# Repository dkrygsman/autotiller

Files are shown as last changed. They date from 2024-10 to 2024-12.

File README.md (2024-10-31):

# Linear Actuator Project

## Overview 
3d modeled and printed linear actuator, all stl files are included and links to parts. Printed with PLA I will eventually make useing PETG when everything is working together.

## Next Steps
Project will include details with motor, h-bridge, and C code for usable functions. Maybe use a stepper motor. 

## Parts
Threaded rod on amazon [Here](https://www.amazon.com/gp/product/B07D7WVN1G/ref=ppx_yo_dt_b_search_asin_title?ie=UTF8&psc=1)

Ten turn potentiometer on amazon (would recommend buying from a name brand) [Here](https://www.amazon.com/gp/product/B079JN626M/ref=ppx_yo_dt_b_search_asin_title?ie=UTF8&psc=1)

Belt pullies on amazon [Here](https://www.amazon.com/gp/product/B07RBNK8LN/ref=ppx_yo_dt_b_search_asin_title?ie=UTF8&th=1)

Belts on amazon [Here](https://www.amazon.com/gp/product/B0BZNSJ34B/ref=ppx_yo_dt_b_search_asin_title?ie=UTF8&th=1)

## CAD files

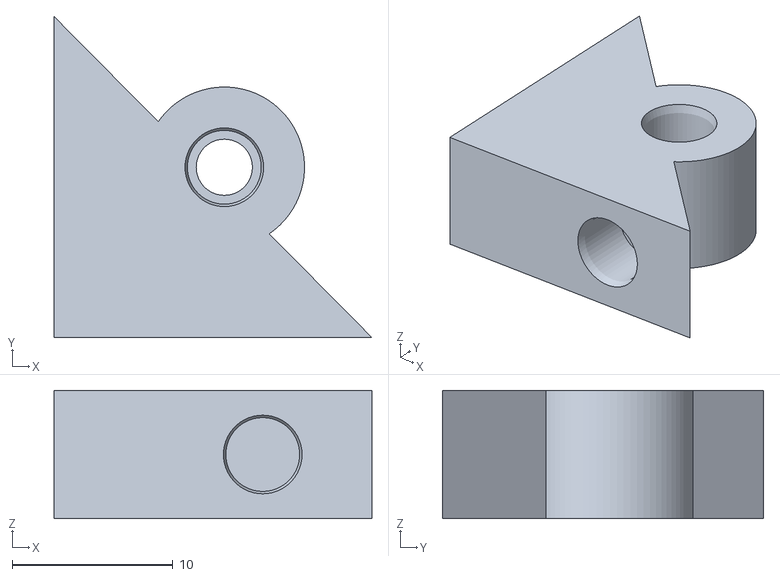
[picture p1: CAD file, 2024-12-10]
stl_files/enclosures/linear_act_wall_to_wall_to_top_bracket.stl
19.8 x 20.0 x 8.00

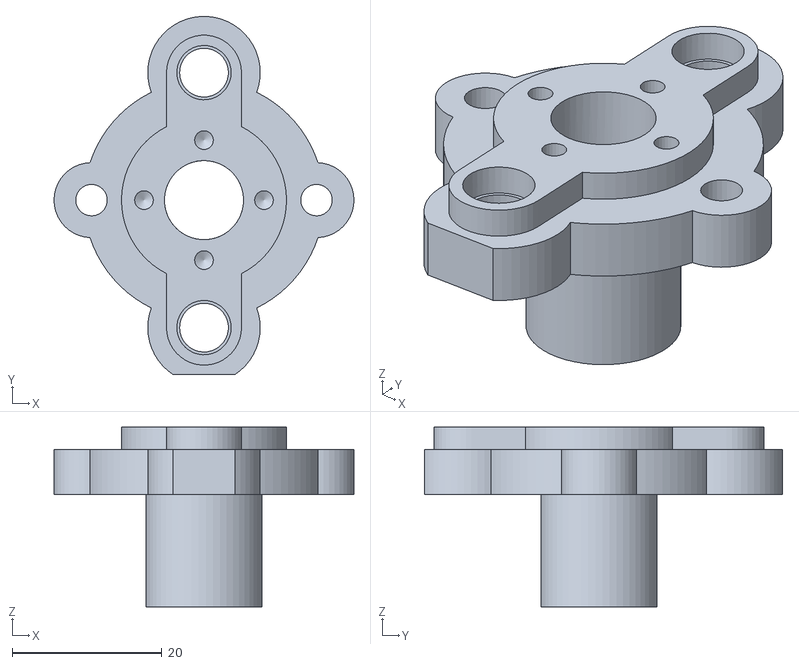
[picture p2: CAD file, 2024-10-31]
stl_files/end_cap.stl
40.0 x 47.7 x 24.0

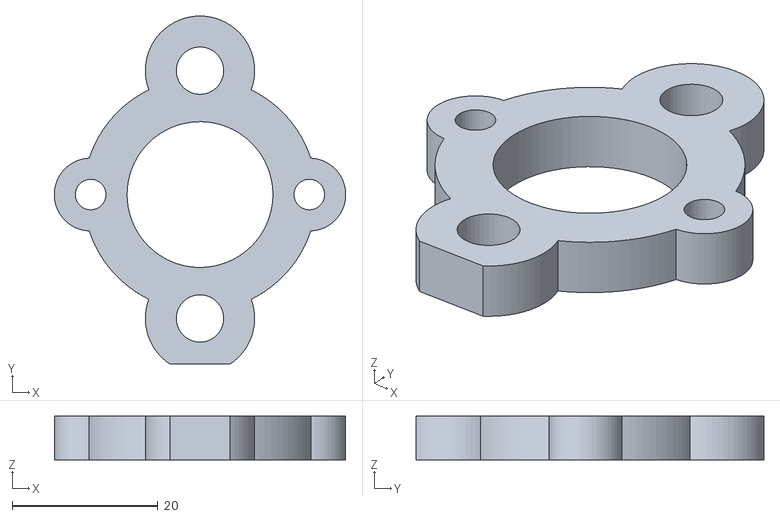
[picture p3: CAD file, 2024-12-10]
stl_files/linear_actuator/slide_end_cap.stl
40.0 x 47.8 x 6.00

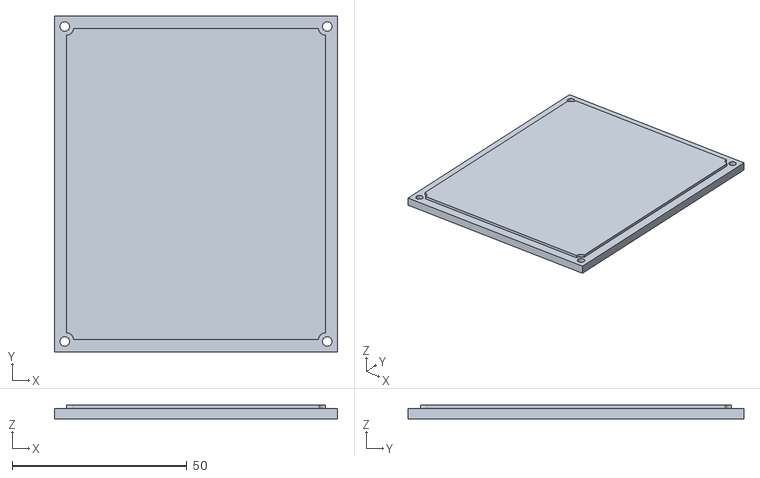
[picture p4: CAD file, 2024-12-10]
stl_files/enclosures/stm32_enclosure_lid.stl
81.0 x 96.0 x 4.00

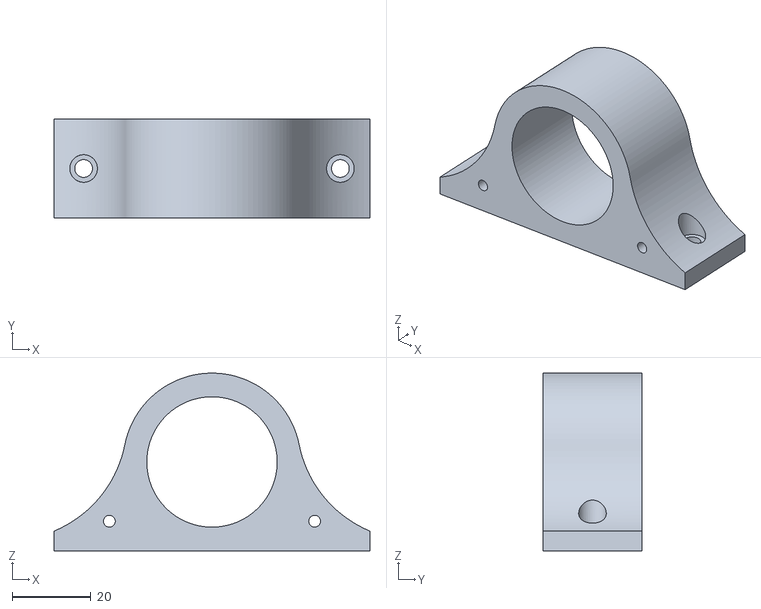
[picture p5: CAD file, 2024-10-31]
stl_files/linear_actuator/motor_holder.stl
80.0 x 25.0 x 45.0

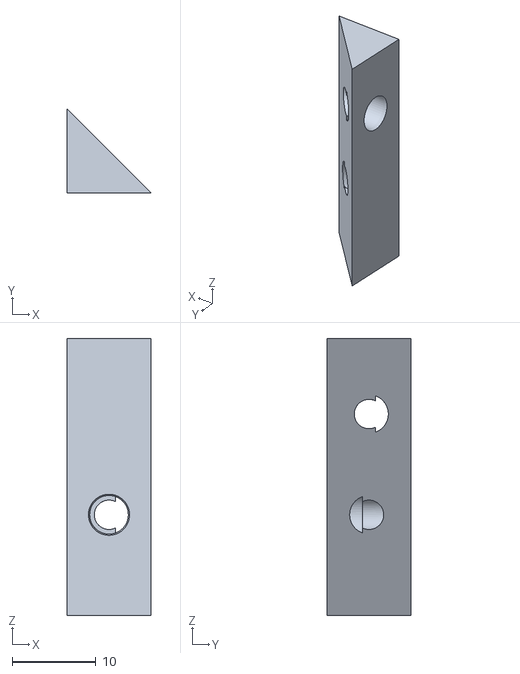
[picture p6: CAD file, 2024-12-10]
stl_files/enclosures/linear_act_base_to_wall_bracket.stl
10.0 x 10.0 x 33.0

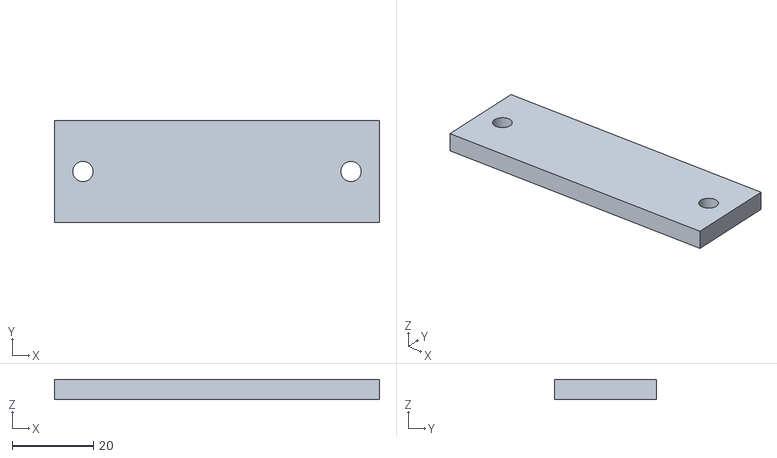
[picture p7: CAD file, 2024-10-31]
stl_files/linear_actuator/motor_base_lifter.stl
80.0 x 25.0 x 5.00

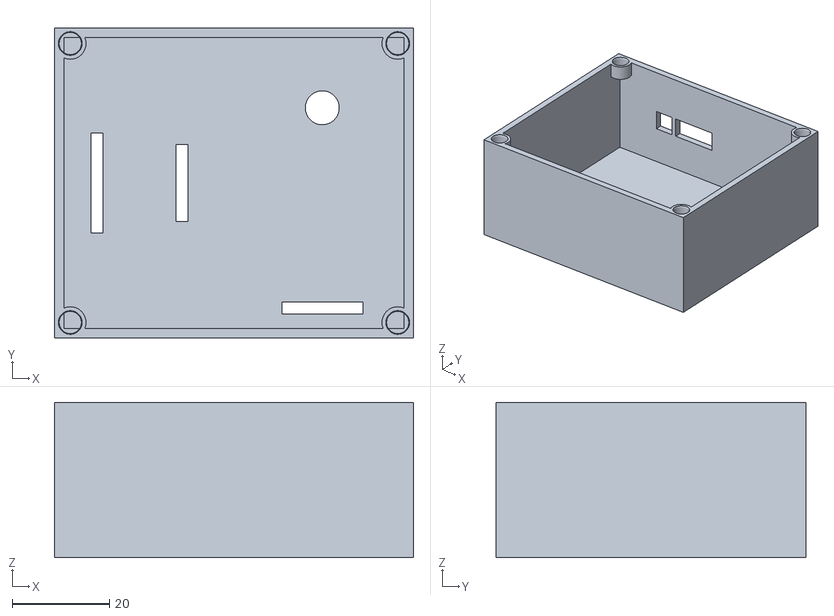
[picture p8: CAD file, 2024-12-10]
stl_files/enclosures/sensor_enclosure.stl
74.0 x 64.0 x 32.0

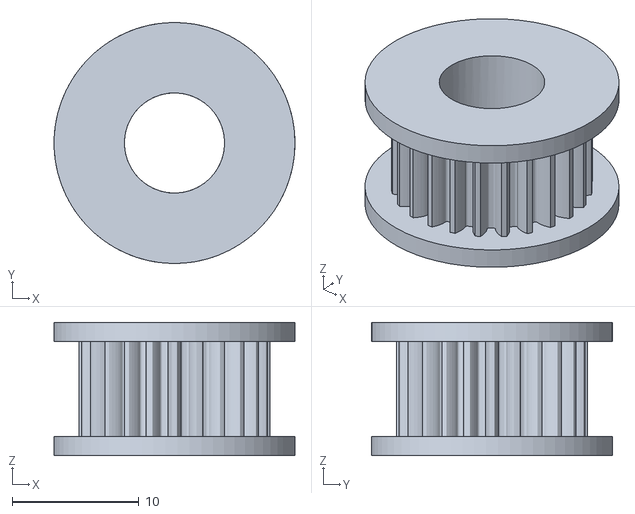
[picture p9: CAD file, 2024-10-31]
stl_files/linear_actuator/threaded_rod_gear7.8.stl
19.0 x 19.0 x 10.5

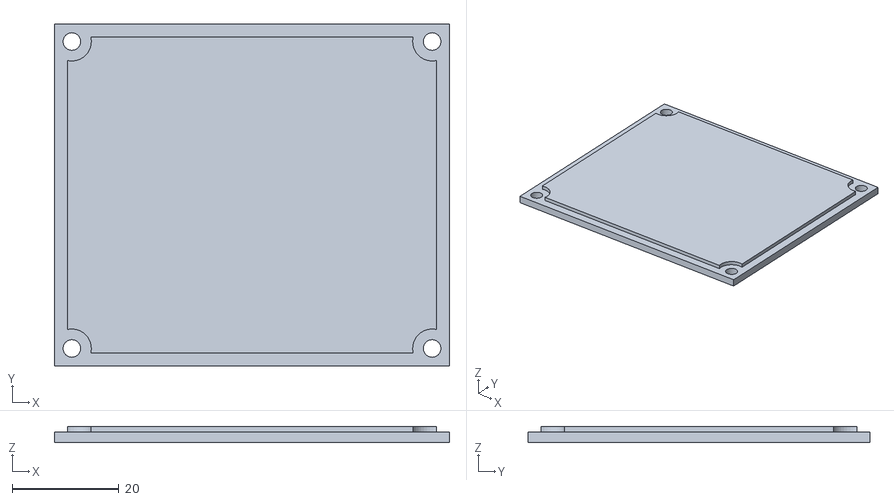
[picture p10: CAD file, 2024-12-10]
stl_files/enclosures/sensor_enclosure_lid.stl
74.0 x 64.0 x 3.00

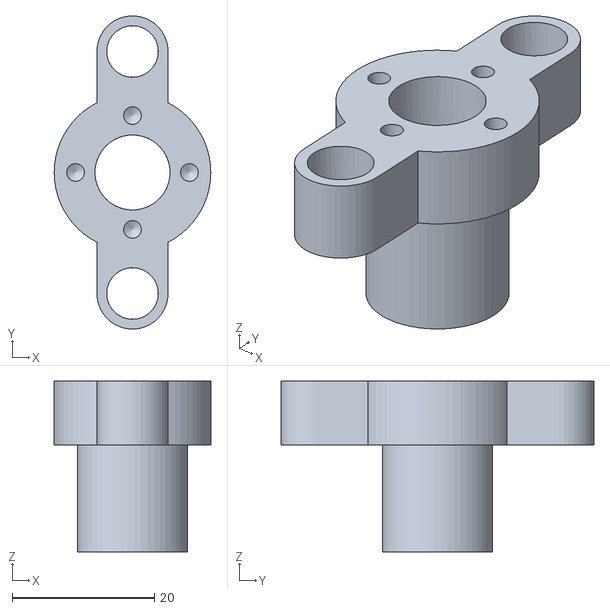
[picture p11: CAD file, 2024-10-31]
stl_files/linear_actuator/slide_rod_slide.stl
22.0 x 44.0 x 24.0

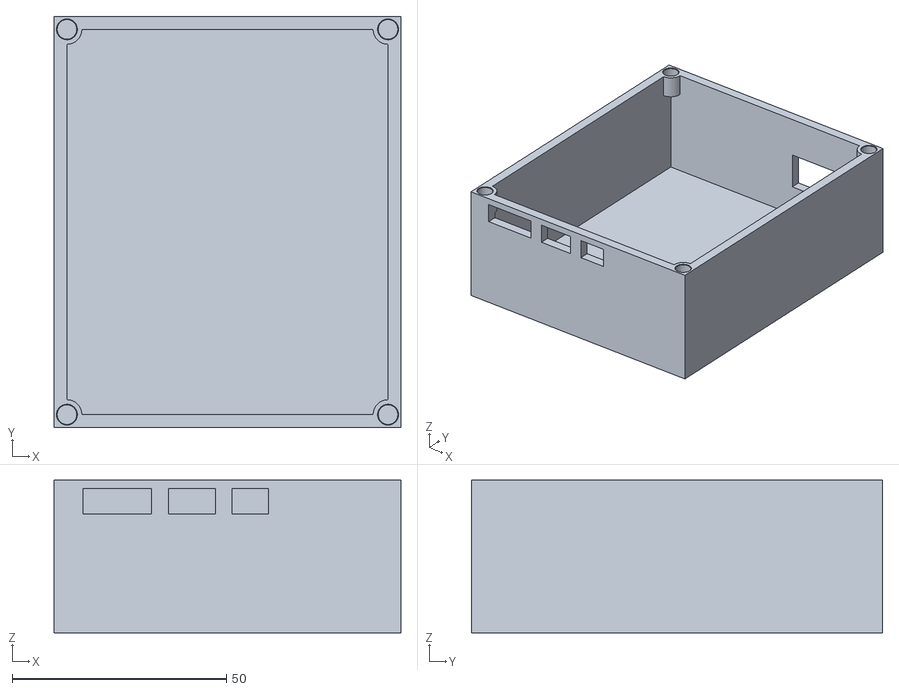
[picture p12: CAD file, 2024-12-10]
stl_files/enclosures/stm32_enclosure.stl
81.0 x 96.0 x 35.7

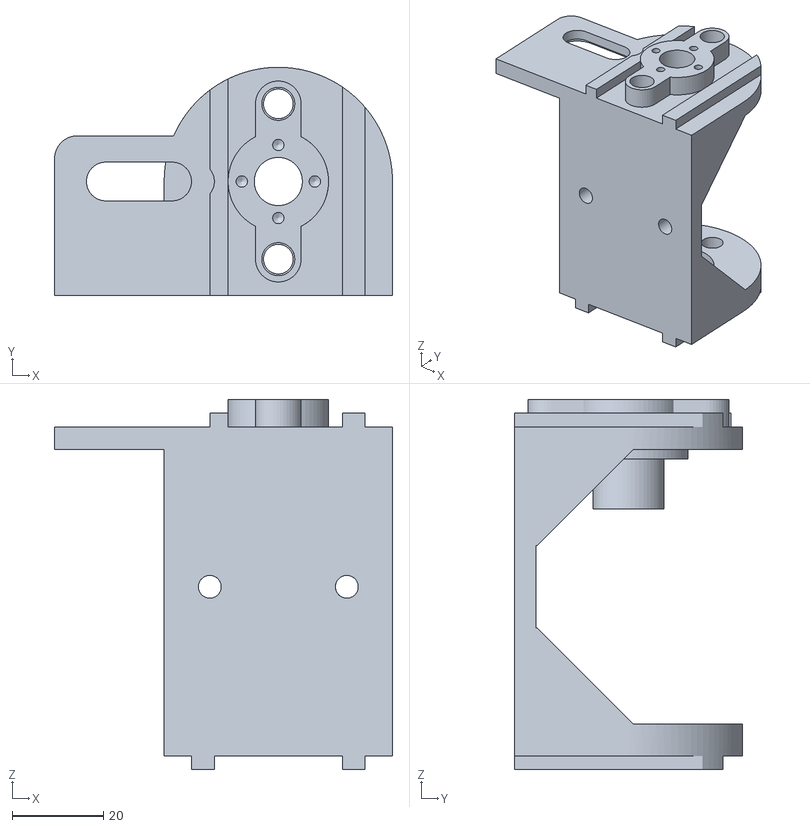
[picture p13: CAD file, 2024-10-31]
stl_files/linear_actuator/linear_act_base.stl
74.0 x 50.0 x 81.0

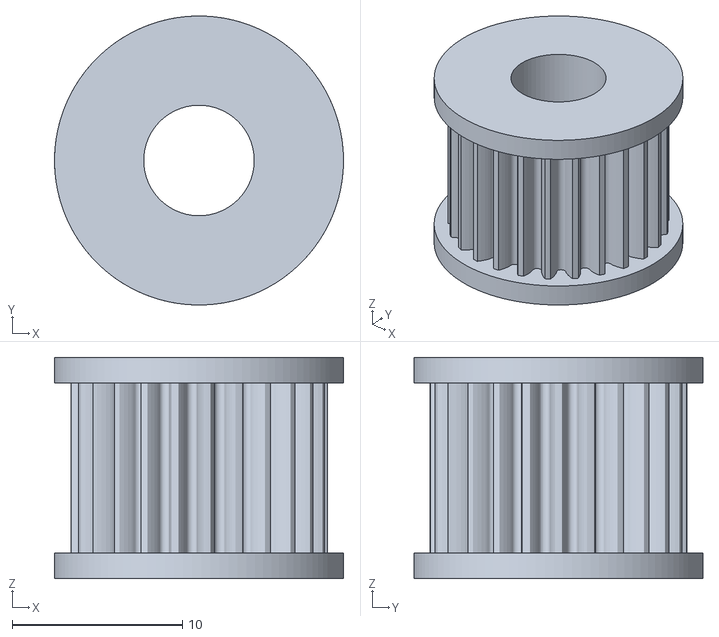
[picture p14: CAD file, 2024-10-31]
stl_files/linear_actuator/pot_gear.stl
17.0 x 17.0 x 13.0

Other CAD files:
stl_files/linear_actuator/threaded_rod_gear7.7.stl

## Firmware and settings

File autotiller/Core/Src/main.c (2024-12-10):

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
/* Includes ------------------------------------------------------------------*/
#include "main.h"

/* USER CODE BEGIN Includes */

#include <stdio.h>
#include <stdlib.h>

#include "fonts.h"
#include "ssd1306.h"

#include "bno055.h"
#include "bno_config.h"

#include "auto_till.h"

/* USER CODE END Includes */

ADC_HandleTypeDef hadc1;

I2C_HandleTypeDef hi2c1;
I2C_HandleTypeDef hi2c2;

UART_HandleTypeDef huart2;

/* USER CODE BEGIN PV */

bno055_t bno;
error_bno err;


uint32_t feedback_pot, offset_pot;
uint32_t yaw, new_yaw, period = 50;

float heading, heading_error, heading_difference, PID_p, PID_i, PID_d;
float heading_prev_error = 0;
float heading_set_point;
float kp = 9, ki = .25, kd = 3300;
float PID_total;

/* USER CODE END PV */

void SystemClock_Config(void);
static void MX_GPIO_Init(void);
static void MX_USART2_UART_Init(void);
static void MX_ADC1_Init(void);
static void MX_I2C1_Init(void);
static void MX_I2C2_Init(void);
/* USER CODE BEGIN 0 */

void ADC_Select_CH0 (void)
{
	ADC_ChannelConfTypeDef sConfig = {0};

	sConfig.Channel = ADC_CHANNEL_0;
	sConfig.Rank = 1;
	sConfig.SamplingTime = ADC_SAMPLETIME_28CYCLES;
	if (HAL_ADC_ConfigChannel(&hadc1, &sConfig) != HAL_OK)
	{
	Error_Handler();
	}
}

void ADC_Select_CH1 (void)
{
	ADC_ChannelConfTypeDef sConfig = {0};

	sConfig.Channel = ADC_CHANNEL_1;
	sConfig.Rank = 1;
	if (HAL_ADC_ConfigChannel(&hadc1, &sConfig) != HAL_OK)
	{
	Error_Handler();
	}
}




/* USER CODE END 0 */

/**
  * @brief  The application entry point.
  * @retval int
  */
int main(void)
{

  /* MCU Configuration--------------------------------------------------------*/

  /* Reset of all peripherals, Initializes the Flash interface and the Systick. */
  HAL_Init();

  /* USER CODE BEGIN Init */

  push_pull_init(GPIOC, GPIO_PIN_7, GPIOA, GPIO_PIN_9);

  /* USER CODE END Init */

  /* Configure the system clock */
  SystemClock_Config();

  /* Initialize all configured peripherals */
  MX_GPIO_Init();
  MX_USART2_UART_Init();
  MX_ADC1_Init();
  MX_I2C1_Init();
  MX_I2C2_Init();
  /* USER CODE BEGIN 2 */


  bno = (bno055_t)
  {
	  .i2c = &hi2c1, .addr = BNO_ADDR, .mode = BNO_MODE_IMU, ._temp_unit = 0,
	  // .ptr = &bno,
  };
  HAL_Delay(1000);

  if ((err = bno055_init(&bno)) == BNO_OK)
    {
    	  printf("[+] BNO055 init success\r\n");
  	  HAL_Delay(100);
    }
    else
    {
  	  printf("[!] BNO055 init failed\r\n");
  	  printf("%s\n", bno055_err_str(err));
  	  Error_Handler();
    }
  	  HAL_Delay(100);
  	  err = bno055_set_unit(&bno, BNO_TEMP_UNIT_C, BNO_GYR_UNIT_DPS, BNO_ACC_UNITSEL_M_S2, BNO_EUL_UNIT_DEG);
    if (err != BNO_OK)
    {
  	  printf("[BNO] Failed to set units. Err: %d\r\n", err);
    }
    else
    {
  	  printf("[BNO] Unit selection success\r\n");
    }

    HAL_Delay(1000);
    bno055_euler_t eul = {0, 0, 0};

    SSD1306_Init();



  /* USER CODE END 2 */

  /* Infinite loop */
  /* USER CODE BEGIN WHILE */
  while (1)
  {

    /* USER CODE END WHILE */

    /* USER CODE BEGIN 3 */


	  ADC_Select_CH0();
	  HAL_ADC_Start(&hadc1);
	  HAL_ADC_PollForConversion(&hadc1, 1000);
	  feedback_pot = HAL_ADC_GetValue(&hadc1);
	  HAL_ADC_Stop(&hadc1);

	  ADC_Select_CH1();
	  HAL_ADC_Start(&hadc1);
	  HAL_ADC_PollForConversion(&hadc1, 1000);
	  offset_pot = HAL_ADC_GetValue(&hadc1);
	  offset_pot = (offset_pot/100) - 20;
	  HAL_ADC_Stop(&hadc1);

	  bno.euler(&bno, &eul);
	  yaw = (int)eul.yaw;				//populate yaw with euler.yaw value
	  yaw = (yaw + 180) % 360;			//modulus for setting first value to 180 instead of 0
	  new_yaw = yaw + offset_pot;		//shifting the heading based off offset

	  heading_set_point = 180;

	  heading = new_yaw;
	  heading_error = heading_set_point - heading;
	  PID_p = kp * heading_error;						//proportional component

	  heading_difference = heading_error - heading_prev_error;
	  PID_d = kd * ((heading_error - heading_prev_error)/ period);		//derivative component

	  if(heading_error > -3 && heading_error < 3)		//integral cutoffs
	  {
		  PID_i = PID_i + (ki * heading_error);				//integral component
	  }
	  else
	  {
		  PID_i = 0;
	  }

	  PID_total = PID_p + PID_i + PID_d;		//combining P, I, and D components



//	  printf("%f  %f  %f  %f  %f\r\n", PID_p, PID_i, PID_d, PID_total, heading_error);
//	  fflush(stdout);
//	  HAL_Delay(2);

//	  printf("%f\t", PID_total);
//	  fflush(stdout);
//	  HAL_Delay(2);

	  PID_total = remap_val(PID_total, -3000, 3000, -400, 1600); 		//remapping values for range and sensitivity
	  feedback_pot = remap_val(feedback_pot, 0, 4100, 101, 1099);	//limits set at 130 and 1070

	  if(PID_total < -200)			//PID limits
	  {
		  PID_total = -200;
	  }
	  if(PID_total > 1400)
	  {
		  PID_total = 1400;
	  }

//	  printf("%f\r\n", PID_total);
//	  fflush(stdout);
//	  HAL_Delay(2);

	  linear_set(feedback_pot, GPIOC, GPIO_PIN_7, GPIOA, GPIO_PIN_9, PID_total);

//	  printf("%f  %ld\r\n", PID_total, feedback_pot);
//	  fflush(stdout);
//	  HAL_Delay(2);

	  char char_buff_1[1000], char_buff_2[1000];
	  sprintf(char_buff_1, "%ld", yaw);
	  sprintf(char_buff_2, "%ld", offset_pot);


	  SSD1306_GotoXY (0,0);
	  SSD1306_Puts ("Yaw:", &Font_7x10, 1);
	  SSD1306_GotoXY (0,30);
	  SSD1306_Puts ("Offset:", &Font_7x10, 1);

	  SSD1306_GotoXY (50,0);
	  SSD1306_Puts (char_buff_1, &Font_7x10, 1);
	  SSD1306_GotoXY (50,30);
	  SSD1306_Puts (char_buff_2, &Font_7x10, 1);
	  SSD1306_UpdateScreen();
	  HAL_Delay (2);
	  SSD1306_Clear();


  }
  /* USER CODE END 3 */
}

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
/* USER CODE BEGIN 4 */

int _write(int file, char *ptr, int len)
{
  (void)file;
  int DataIdx;

  for (DataIdx = 0; DataIdx < len; DataIdx++)
  {
	  ITM_SendChar(*ptr++);
  }
  return len;
}

/* USER CODE END 4 */
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


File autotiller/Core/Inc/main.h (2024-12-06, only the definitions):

#define B1_Pin GPIO_PIN_13
#define B1_GPIO_Port GPIOC
#define feedback_pot_Pin GPIO_PIN_0
#define feedback_pot_GPIO_Port GPIOA
#define offset_pot_Pin GPIO_PIN_1
#define offset_pot_GPIO_Port GPIOA
#define USART_TX_Pin GPIO_PIN_2
#define USART_TX_GPIO_Port GPIOA
#define USART_RX_Pin GPIO_PIN_3
#define USART_RX_GPIO_Port GPIOA
#define LD2_Pin GPIO_PIN_5
#define LD2_GPIO_Port GPIOA
#define OLED_SCL_Pin GPIO_PIN_10
#define OLED_SCL_GPIO_Port GPIOB
#define forward_Pin GPIO_PIN_7
#define forward_GPIO_Port GPIOC
#define reverse_Pin GPIO_PIN_9
#define reverse_GPIO_Port GPIOA
#define TMS_Pin GPIO_PIN_13
#define TMS_GPIO_Port GPIOA
#define TCK_Pin GPIO_PIN_14
#define TCK_GPIO_Port GPIOA
#define SWO_Pin GPIO_PIN_3
#define SWO_GPIO_Port GPIOB
#define bno_scl_Pin GPIO_PIN_6
#define bno_scl_GPIO_Port GPIOB
#define bno_sda_Pin GPIO_PIN_7
#define bno_sda_GPIO_Port GPIOB
#define OLED_SDA_Pin GPIO_PIN_9
#define OLED_SDA_GPIO_Port GPIOB

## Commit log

2024-10-31 is it an stl file?
    [pot_gear.stl]
2024-10-31 rest of stl files added
    [end_cap.stl, linear_act_base.stl, motor_base_lifter.stl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]
2024-10-31 moving stl files into folder
    [end_cap.stl, linear_act_base.stl, motor_base_lifter.stl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]
2024-10-31 working 3 channel ADC using DMA
2024-10-31 PID controller working with pot input k values
2024-11-01 added servo and PID controller works with it
2024-11-01 OLED added which displays P, I, D values and yaw value
2024-12-06 added combined project
    [Body1.stl, test_thread.stl]
2024-12-08 PID_total not working when yaw goes negative bug has been found and fixed
    [auto_till.c, main.c]
2024-12-10 adding all stls
    [Body1.stl, end_cap.stl, linear_act_base.stl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]
2024-12-11 all stls and schematic added
    [autotillerki.kicad_sch, end_cap.stl]

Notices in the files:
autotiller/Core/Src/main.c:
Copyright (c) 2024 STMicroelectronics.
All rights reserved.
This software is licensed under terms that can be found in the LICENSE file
